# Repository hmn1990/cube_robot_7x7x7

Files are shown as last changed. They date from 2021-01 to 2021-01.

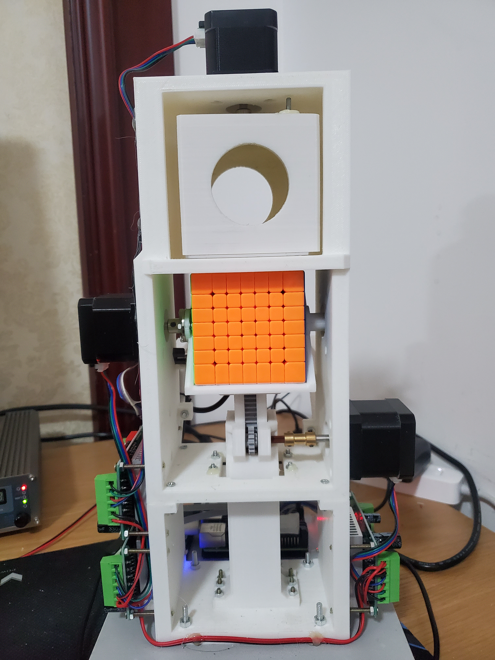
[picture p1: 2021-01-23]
实物图/20210123_192739.jpg

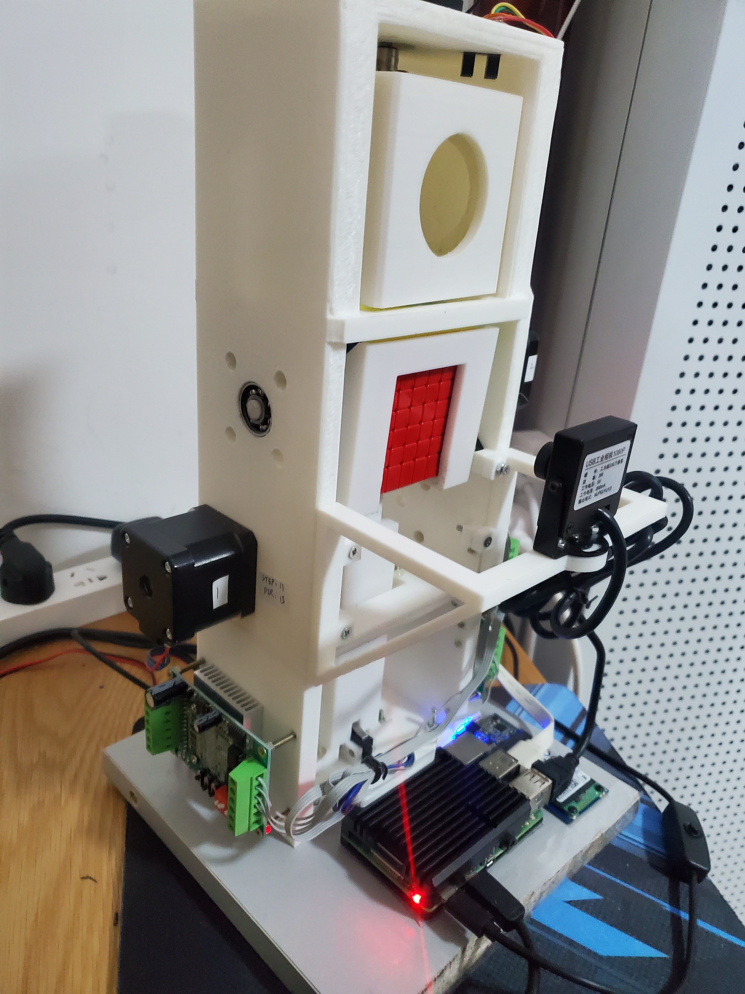
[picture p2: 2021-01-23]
实物图/20210123_192805.jpg

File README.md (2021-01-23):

# cube_robot_7x7x7

#### 介绍
使用树莓派控制的魔方机器人，可以在平均5-6分钟的时间内完成7阶魔方的还原。
使用C + Python开发，含有结构设计、软件部分，实物照片，演示视频。
算法使用rubiks-cube-NxNxN-solver，可还原任意阶数魔方，在原版基础上略有修改。

#### 系统架构
树莓派--+--步进电机驱动器--升降控制电机
       +--升降零点微动开关
       |
       +--步进电机驱动器--翻转控制电机
       +--翻转零点光电开关
       |
       +--步进电机驱动器--旋转控制电机	
       +--旋转零点光电开关
       |
       +--USB摄像头（120度视角）
       +--键盘、鼠标、显示器
       +--USB转mSATA--固态硬盘（可选配置，对提高求解速度有很大的作用）

#### 演示视频：
七阶魔方
http://v.youku.com/v_show/id_XNTA3NDcyNjU5Ng==.html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
三阶魔方
http://v.youku.com/v_show/id_XNDg5NTM2OTg5Mg==.html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

#### 配置与运行步骤：
1、安装python3-opencv
sudo apt-get install python3-opencv

2、安装ckociemba
cd kociemba/
make
sudo make install

3、安装rubiks-cube-NxNxN-solver（该版本相对于原始版本有修改，添加了边计算边输出中间结果的功能，去除了对python venv的需求）
make init
./rubiks-cube-solver.py --state DBDBDDFBDDLUBDLFRFRBRLLDUFFDUFRBRDFDRUFDFDRDBDBULDBDBDBUFBUFFFULLFLDURRBBRRBRLFUUUDUURBRDUUURFFFLRFLRLDLBUFRLDLDFLLFBDFUFRFFUUUFURDRFULBRFURRBUDDRBDLLRLDLLDLUURFRFBUBURBRUDBDDLRBULBULUBDBBUDRBLFFBLRBURRUFULBRLFDUFDDBULBRLBUFULUDDLLDFRDRDBBFBUBBFLFFRRUFFRLRRDRULLLFRLFULBLLBBBLDFDBRBFDULLULRFDBR
第二个步骤很慢，需要联网下载大量数据，解压后需要占用6.2GB空间。

4、修改/boot/cmdline.txt 在末尾添加isolcpus=3，然后重启，可选步骤，可改善运行时卡顿的问题

5、编译并且加载内核模块，在此之前请安装好linux内核头文件
cd cube_robot_kernel_module
make
sudo make load
cd ..
如需调整电机旋转速度，修改step_moter.py，make table后重新编译内核模块

6、运行主程序
./cube_robot.py
等待出现预览画面后，放入魔方，按空格键开始还原，ESC退出。

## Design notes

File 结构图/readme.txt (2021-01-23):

装配过程发现以下问题
1 升降杆间隙太小，需要打磨
2 翻转架多了一个横梁，据掉
3 部分螺丝不大好拧到

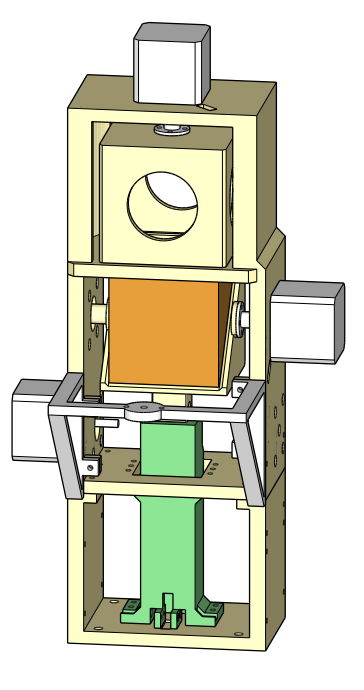
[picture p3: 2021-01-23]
结构图/魔方机器人.PNG

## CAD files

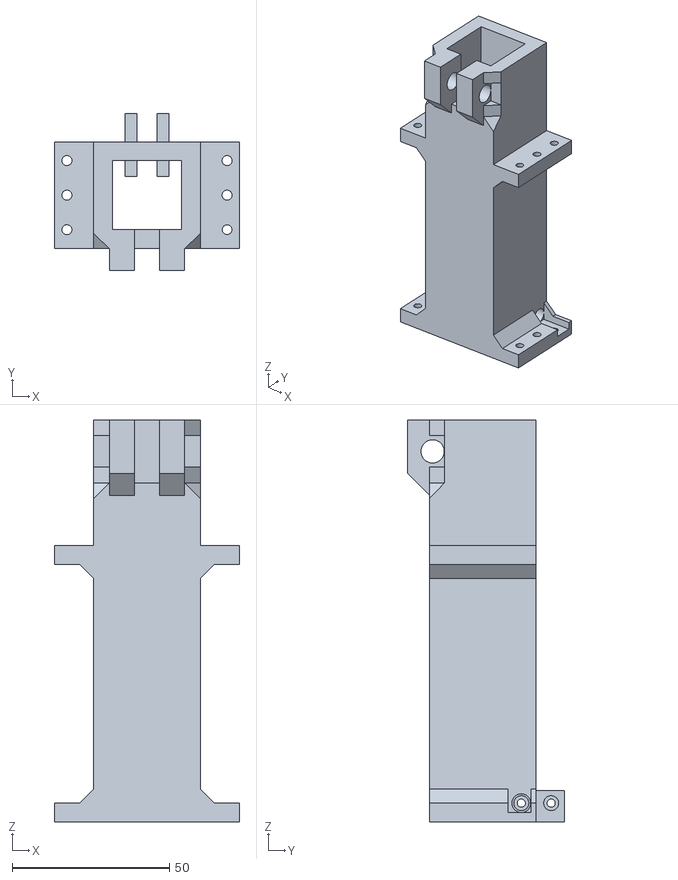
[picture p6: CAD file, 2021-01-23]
结构图/升降杆套筒.stl
59.0 x 50.0 x 128.0

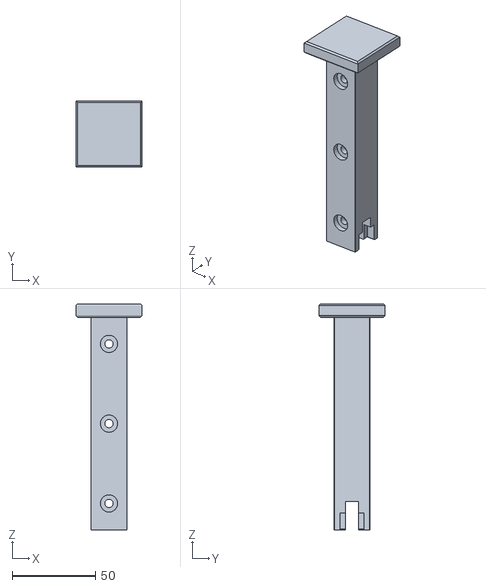
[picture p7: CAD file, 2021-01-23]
结构图/升降杆.stl
40.0 x 40.0 x 136.0

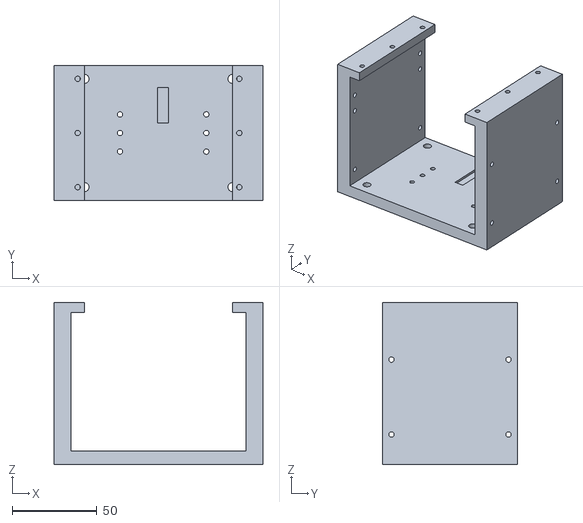
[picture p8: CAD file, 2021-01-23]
结构图/下层框架.stl
123.5 x 80.0 x 96.0

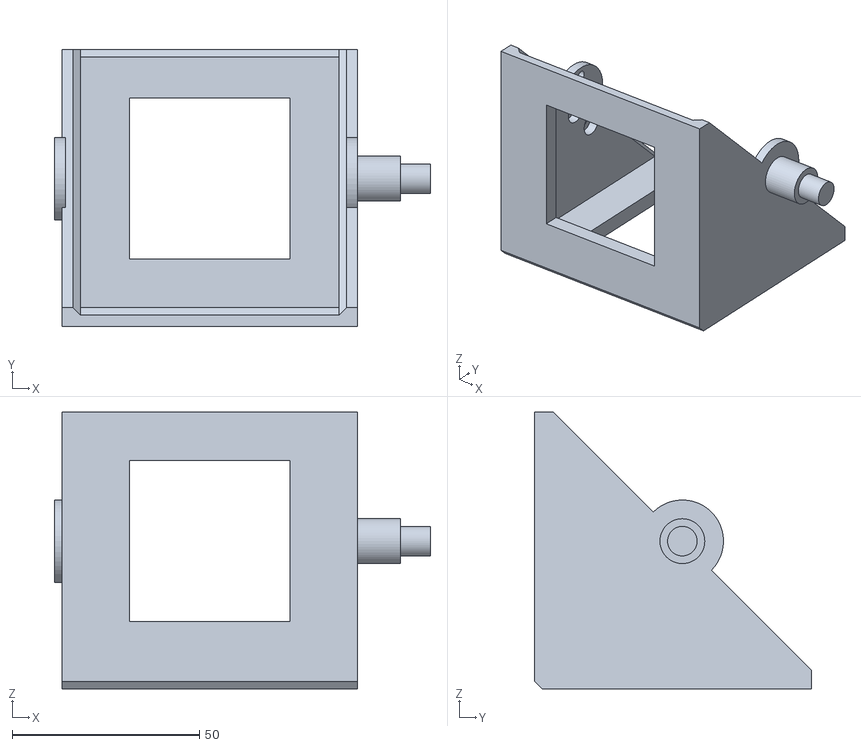
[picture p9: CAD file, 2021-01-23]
结构图/翻转架.stl
100.5 x 74.0 x 74.0

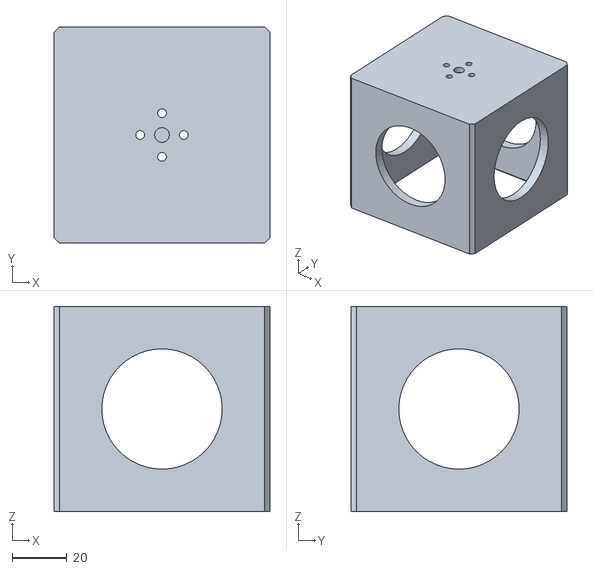
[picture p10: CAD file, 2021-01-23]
结构图/魔方笼.stl
79.0 x 79.0 x 75.0

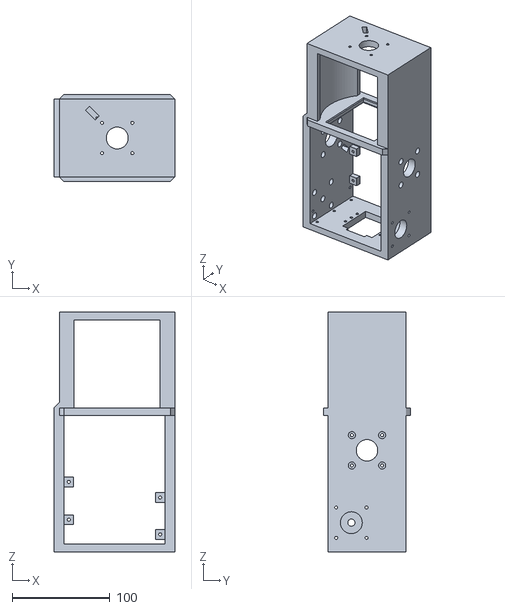
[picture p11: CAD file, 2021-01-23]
结构图/上层框架.stl
123.5 x 89.0 x 245.5

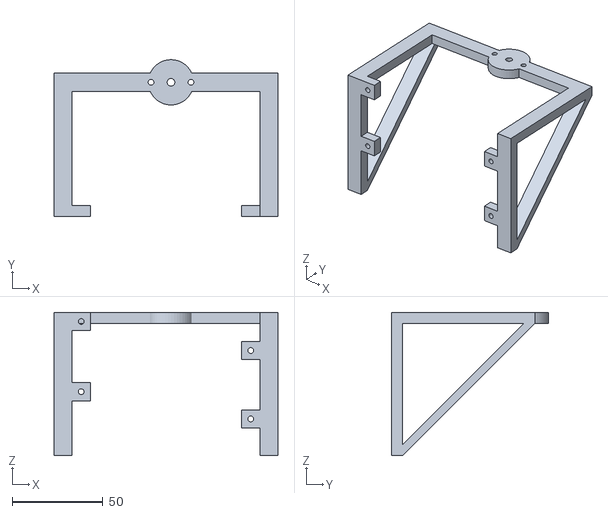
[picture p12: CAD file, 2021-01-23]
结构图/摄像头支架.stl
123.5 x 86.4 x 78.9

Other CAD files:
结构图/魔方机器人（七阶）.skp

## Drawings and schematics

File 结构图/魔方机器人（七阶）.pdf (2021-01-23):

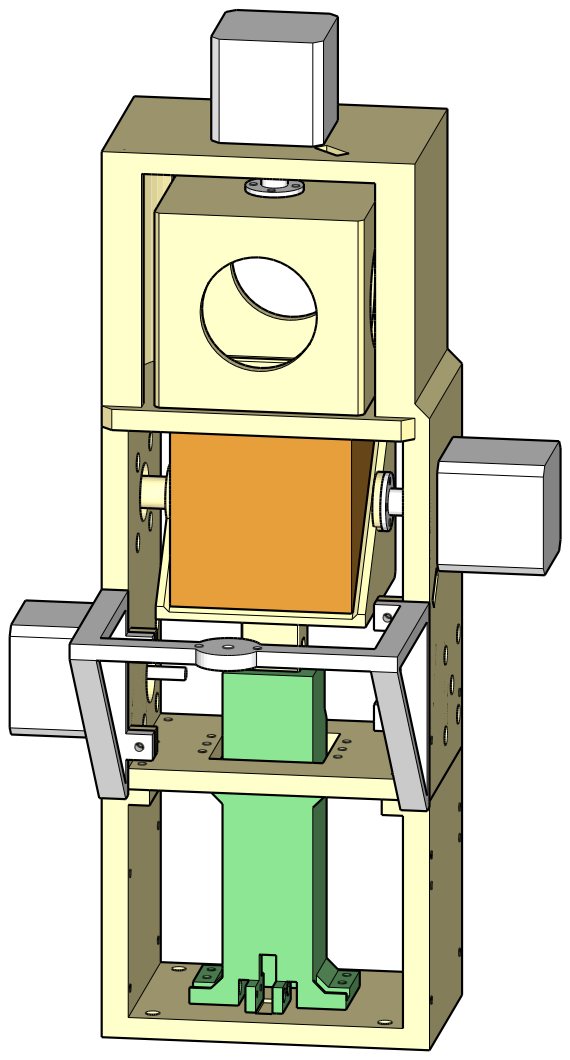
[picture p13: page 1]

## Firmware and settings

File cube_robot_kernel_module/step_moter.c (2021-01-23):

#include <linux/module.h>
#include <linux/kernel.h>
#include <linux/init.h>
#include <asm/delay.h>
#include <asm/io.h>
//#include <linux/slab.h> 
#include <linux/fs.h>
#include <asm/uaccess.h>    /* for put_user */
#include <linux/cdev.h>
#include <linux/errno.h>
#include <asm/current.h>
#include <linux/sched.h>
#include <linux/device.h>


#include "step_moter.h"
#include "step_tab.h"

MODULE_LICENSE("GPL"); 
MODULE_VERSION("0.1"); 

static uint32_t* gpio_base = 0;

/* Read input pin */
static uint8_t gpio_read(uint8_t pin)
{
    volatile uint32_t* paddr = gpio_base + BCM2835_GPLEV0/4 + pin/32;
    uint8_t shift = pin % 32;
    uint32_t value = ioread32(paddr);
    return (value & (1 << shift)) ? HIGH : LOW;
}

/* Set output pin */
static void gpio_set(uint8_t pin)
{
    volatile uint32_t* paddr = gpio_base + BCM2835_GPSET0/4 + pin/32;
    uint8_t shift = pin % 32;
    iowrite32(1 << shift, paddr);
}

/* Clear output pin */
static void gpio_clr(uint8_t pin)
{
    volatile uint32_t* paddr = gpio_base + BCM2835_GPCLR0/4 + pin/32;
    uint8_t shift = pin % 32;
    iowrite32(1 << shift, paddr);
}

/* Set the pullup/down resistor for a pin */
static void gpio_set_pud(uint8_t pin, uint8_t pud)
{
        int shiftbits = (pin & 0xf) << 1;
        uint32_t bits;
        uint32_t pull;
        volatile uint32_t* paddr;
        switch (pud)
        {
           case BCM2835_GPIO_PUD_OFF:  pull = 0; break;
           case BCM2835_GPIO_PUD_UP:   pull = 1; break;
           case BCM2835_GPIO_PUD_DOWN: pull = 2; break;
           default: return;
        }
        paddr = gpio_base + BCM2835_GPPUPPDN0/4 + (pin >> 4);
        
        bits = ioread32( paddr );
        bits &= ~(3 << shiftbits);
        bits |= (pull << shiftbits);
        iowrite32(bits, paddr);
}

/* set gpio input or output mode */
static void gpio_fsel(uint8_t pin, uint8_t mode)
{
    /* Function selects are 10 pins per 32 bit word, 3 bits per pin */
    volatile uint32_t* paddr = gpio_base + BCM2835_GPFSEL0/4 + (pin/10);
    uint8_t   shift = (pin % 10) * 3;
    uint32_t  mask = BCM2835_GPIO_FSEL_MASK << shift;
    uint32_t  value = mode << shift;
    
    uint32_t v = ioread32(paddr);
    v = (v & ~mask) | (value & mask);
    iowrite32(v, paddr);
}

static void gpio_init(void)
{
  gpio_fsel (M3_STEP, BCM2835_GPIO_FSEL_OUTP);
  gpio_fsel (M3_DIR,  BCM2835_GPIO_FSEL_OUTP);
  gpio_fsel (M2_STEP, BCM2835_GPIO_FSEL_OUTP);
  gpio_fsel (M2_DIR,  BCM2835_GPIO_FSEL_OUTP);
  gpio_fsel (M1_STEP, BCM2835_GPIO_FSEL_OUTP);
  gpio_fsel (M1_DIR,  BCM2835_GPIO_FSEL_OUTP);
  gpio_clr(M1_STEP);
  gpio_clr(M2_STEP);
  gpio_clr(M3_STEP);
  gpio_fsel(M3_SWITCH, BCM2835_GPIO_FSEL_INPT);
  gpio_fsel(M2_SWITCH, BCM2835_GPIO_FSEL_INPT);
  gpio_fsel(M1_SWITCH, BCM2835_GPIO_FSEL_INPT);
  gpio_set_pud(M1_SWITCH, BCM2835_GPIO_PUD_UP);
}


// 步进电机控制
// 加速算法参考http://hwml.com/LeibRamp.htm
static void move(int gpio_pin, int length, int *array, int step)
{
  int p, i;
  unsigned long flags;
  local_irq_save(flags);
  for (i=0; i<step; i++){
    if (i < length && i < step / 2)
       p = array[i];
    else if(step - 1 - i < length)
       p = array[step - 1 - i];
    else
       p = array[length - 1];
    // pull high
    gpio_set(gpio_pin);
    udelay(p);
    // pull low
    gpio_clr(gpio_pin);
    udelay(p);
  }
  local_irq_restore(flags);
}

// 回零点
static void m3_zero(void)
{
  int stat,stat_old,i;
  gpio_set(M3_DIR);
  move(M3_STEP, m3_length, m3_array, 128);
  stat_old = gpio_read(M3_SWITCH);
  gpio_clr(M3_DIR);
  for(i=0;i<3200;i++){
    move(M3_STEP, m3_length, m3_array,1);
    stat = gpio_read(M3_SWITCH);
    if(stat == LOW && stat_old == HIGH){
      break;
    }
    stat_old = stat;
  }
  move(M3_STEP, m3_length, m3_array, 50);
}
static void m2_zero(void)
{
  int stat,stat_old,i;
  gpio_set(M2_DIR);
  move(M2_STEP, m2_length, m2_array, 128);
  stat_old = gpio_read(M2_SWITCH);
  gpio_clr(M2_DIR);
  for(i=0;i<1600;i++){
    move(M2_STEP, m2_length, m2_array, 1);
    stat = gpio_read(M2_SWITCH);
    if(stat == LOW && stat_old == HIGH){
      break;
    }
    stat_old = stat;
  }
  move(M2_STEP, m2_length, m2_array, 36);
}
static void m1_zero(void)
{
  int stat,stat_old,i;
  gpio_set(M1_DIR);
  move(M1_STEP, m1_length, m1_array,  48);
  stat_old = gpio_read(M1_SWITCH);
  gpio_clr(M1_DIR);
  for(i=0;i<1200;i++){
    move(M1_STEP, m1_length, m1_array,  1);
    stat = gpio_read(M1_SWITCH);
    if(stat == LOW && stat_old == HIGH){
      break;
    }
    stat_old = stat;
  }
  move(M1_STEP, m1_length, m1_array,  12);
}

static void udelay_test(int x)
{
  unsigned long flags;
  unsigned int time_start, time_end;
  int i, diff;
  int avg_val = 0;
  int temp[16] = {0};
  
  local_irq_save(flags);
  for(i=0;i<100;i++){
    time_start = get_cycles();
    udelay(80);
    time_end = get_cycles();
    avg_val += time_end - time_start;
  }
  avg_val /= 100;
  for(i=0;i<x;i++){
    time_start = get_cycles();
    udelay(80);
    time_end = get_cycles();
    diff = time_end - time_start - avg_val;
    diff = (diff + 40) / 5;
    if(diff > 15)
      diff = 15;
    else if(diff < 0)
      diff = 0;
    temp[diff] += 1; 
  }
  local_irq_restore(flags);
  
  printk(KERN_INFO "avg delay cycles of udelay(80) is %d\n", avg_val);
  for(i=0;i<16;i++){
    printk(KERN_INFO "%d ~ %d error is %d\n", i*5-40,i*5+4-40,temp[i]);
  }
}

static int Device_Open = 0; 
static char *msg_Ptr;
static char cmd_buffer[65536]={0};

static int device_open(struct inode *inode, struct file *file)
{
    if (Device_Open)
        return -EBUSY;
    Device_Open++;
    
    msg_Ptr = cmd_buffer;
    
    try_module_get(THIS_MODULE);
    return 0;
}

static int device_release(struct inode *inode, struct file *file)
{
    Device_Open--;
    module_put(THIS_MODULE);
    return 0;
}

static ssize_t device_read(struct file *file, char *buffer, size_t length, loff_t *offset)
{
    int bytes_read = 0;

    if (*msg_Ptr == 0)
        return 0;

    while (length && *msg_Ptr) {
        put_user(*(msg_Ptr++), buffer++);
        length--;
        bytes_read++;
    }

    return bytes_read;
}
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

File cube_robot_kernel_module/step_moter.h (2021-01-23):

#ifndef STEP_MOTER_H
#define STEP_MOTER_H


// 不细分一圈200个脉冲
// 步进电机M1 2细分
#define M1_STEP      17 //11pin
#define M1_DIR       27 //13pin
#define M1_SWITCH    4  //7pin

// 步进电机M2 16细分
#define M2_STEP      22 //15pin
#define M2_DIR       10 //19pin
#define M2_SWITCH    2  //3pin

// 步进电机M3 16细分
#define M3_STEP      9  //21pin
#define M3_DIR       11 //23pin
#define M3_SWITCH    3  //5

// GPIO控制器地址,参考/proc/iomem
#define RPI4_GPIO_ADDR 0xfe200000
#define RPI4_GPIO_SIZE 256

/*! This means pin HIGH, true, 3.3volts on a pin. */
#define HIGH 0x1
/*! This means pin LOW, false, 0volts on a pin. */
#define LOW  0x0

/* Defines for GPIO
   The BCM2835 has 54 GPIO pins.
   BCM2835 data sheet, Page 90 onwards.
*/
/*! GPIO register offsets from BCM2835_GPIO_BASE. 
  Offsets into the GPIO Peripheral block in bytes per 6.1 Register View 
*/
#define BCM2835_GPFSEL0                      0x0000 /*!< GPIO Function Select 0 */
#define BCM2835_GPFSEL1                      0x0004 /*!< GPIO Function Select 1 */
#define BCM2835_GPFSEL2                      0x0008 /*!< GPIO Function Select 2 */
#define BCM2835_GPFSEL3                      0x000c /*!< GPIO Function Select 3 */
#define BCM2835_GPFSEL4                      0x0010 /*!< GPIO Function Select 4 */
#define BCM2835_GPFSEL5                      0x0014 /*!< GPIO Function Select 5 */
#define BCM2835_GPSET0                       0x001c /*!< GPIO Pin Output Set 0 */
#define BCM2835_GPSET1                       0x0020 /*!< GPIO Pin Output Set 1 */
#define BCM2835_GPCLR0                       0x0028 /*!< GPIO Pin Output Clear 0 */
#define BCM2835_GPCLR1                       0x002c /*!< GPIO Pin Output Clear 1 */
#define BCM2835_GPLEV0                       0x0034 /*!< GPIO Pin Level 0 */
#define BCM2835_GPLEV1                       0x0038 /*!< GPIO Pin Level 1 */
#define BCM2835_GPEDS0                       0x0040 /*!< GPIO Pin Event Detect Status 0 */
#define BCM2835_GPEDS1                       0x0044 /*!< GPIO Pin Event Detect Status 1 */
#define BCM2835_GPREN0                       0x004c /*!< GPIO Pin Rising Edge Detect Enable 0 */
#define BCM2835_GPREN1                       0x0050 /*!< GPIO Pin Rising Edge Detect Enable 1 */
#define BCM2835_GPFEN0                       0x0058 /*!< GPIO Pin Falling Edge Detect Enable 0 */
#define BCM2835_GPFEN1                       0x005c /*!< GPIO Pin Falling Edge Detect Enable 1 */
#define BCM2835_GPHEN0                       0x0064 /*!< GPIO Pin High Detect Enable 0 */
#define BCM2835_GPHEN1                       0x0068 /*!< GPIO Pin High Detect Enable 1 */
#define BCM2835_GPLEN0                       0x0070 /*!< GPIO Pin Low Detect Enable 0 */
#define BCM2835_GPLEN1                       0x0074 /*!< GPIO Pin Low Detect Enable 1 */
#define BCM2835_GPAREN0                      0x007c /*!< GPIO Pin Async. Rising Edge Detect 0 */
#define BCM2835_GPAREN1                      0x0080 /*!< GPIO Pin Async. Rising Edge Detect 1 */
#define BCM2835_GPAFEN0                      0x0088 /*!< GPIO Pin Async. Falling Edge Detect 0 */
#define BCM2835_GPAFEN1                      0x008c /*!< GPIO Pin Async. Falling Edge Detect 1 */
#define BCM2835_GPPUD                        0x0094 /*!< GPIO Pin Pull-up/down Enable */
#define BCM2835_GPPUDCLK0                    0x0098 /*!< GPIO Pin Pull-up/down Enable Clock 0 */
#define BCM2835_GPPUDCLK1                    0x009c /*!< GPIO Pin Pull-up/down Enable Clock 1 */

/* 2711 has a different method for pin pull-up/down/enable  */
#define BCM2835_GPPUPPDN0                    0x00e4 /* Pin pull-up/down for pins 15:0  */
#define BCM2835_GPPUPPDN1                    0x00e8 /* Pin pull-up/down for pins 31:16 */
#define BCM2835_GPPUPPDN2                    0x00ec /* Pin pull-up/down for pins 47:32 */
#define BCM2835_GPPUPPDN3                    0x00f0 /* Pin pull-up/down for pins 57:48 */

/*!   \brief bcm2835PortFunction
  Port function select modes for bcm2835_gpio_fsel()
*/
typedef enum
{
    BCM2835_GPIO_FSEL_INPT  = 0x00,   /*!< Input 0b000 */
    BCM2835_GPIO_FSEL_OUTP  = 0x01,   /*!< Output 0b001 */
    BCM2835_GPIO_FSEL_ALT0  = 0x04,   /*!< Alternate function 0 0b100 */
    BCM2835_GPIO_FSEL_ALT1  = 0x05,   /*!< Alternate function 1 0b101 */
    BCM2835_GPIO_FSEL_ALT2  = 0x06,   /*!< Alternate function 2 0b110, */
    BCM2835_GPIO_FSEL_ALT3  = 0x07,   /*!< Alternate function 3 0b111 */
    BCM2835_GPIO_FSEL_ALT4  = 0x03,   /*!< Alternate function 4 0b011 */
    BCM2835_GPIO_FSEL_ALT5  = 0x02,   /*!< Alternate function 5 0b010 */
    BCM2835_GPIO_FSEL_MASK  = 0x07    /*!< Function select bits mask 0b111 */
} bcm2835FunctionSelect;

/*! \brief bcm2835PUDControl
  Pullup/Pulldown defines for bcm2835_gpio_pud()
*/
typedef enum
{
    BCM2835_GPIO_PUD_OFF     = 0x00,   /*!< Off ? disable pull-up/down 0b00 */
    BCM2835_GPIO_PUD_DOWN    = 0x01,   /*!< Enable Pull Down control 0b01 */
    BCM2835_GPIO_PUD_UP      = 0x02    /*!< Enable Pull Up control 0b10  */
} bcm2835PUDControl;


#endif
